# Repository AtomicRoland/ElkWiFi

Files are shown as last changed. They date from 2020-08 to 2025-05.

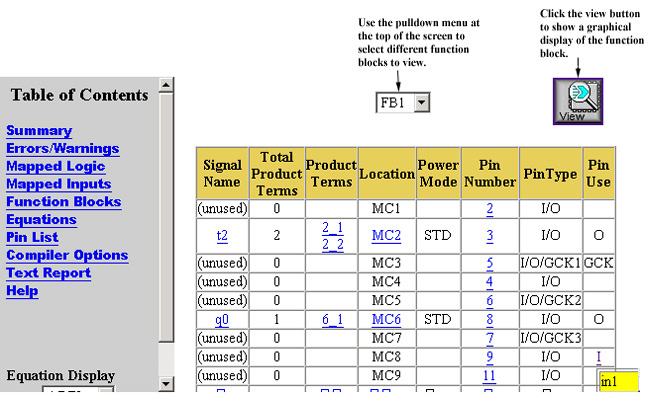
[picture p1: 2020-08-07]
cpld/nco_html/fit/xml5.jpg

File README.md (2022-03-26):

# Introduction

This project is a WiFi interface module for the Acorn Electron. It's a cartridge that fits into a Plus-1 socket. The cartridge contains a ROM for the necessary drivers and utility commands. There's also 128 kB paged RAM available for buffering and storing incoming data. The WiFi is handled by the famous ESP8266 module. This is controlled by a dual UART 16C2552.

# WARNINGS

## 1. Security
The Acorn Electron is in no way a secure device, nor is the software for the WiFi module. When using the commands or driver, usernames and passwords may be kept in memory.

## 2. Baud rate changes may brick the ESP8266
The default transmission speed for the ESP8266 is 115,200 baud. The Electron can handle data transfers at this speed. Do not try to change this speed because the ESP8266 might accept your command but does not always perform it correctly. You might end up with a module that communicates at an unknown serial speed. The only remedy to fix that is to flash the device (or replace it, after all, they cost only about £1.00).

# COMPATIBILITY

This cartridge is tested with an Acorn Electron and a standard Acorn Plus-1 expansion module. It is also tested with an Acorn Plus-1 and a Pres Plus-1 ROM. Both configurations work perfectly.

*Known issues:*
 * With a Pres AP6 ROM in a Plus-1 there is a slight corruption on the screen after a hard reset. The cartridge still works as expected.
 * The CPLD is configured to detect whether it is installed in a BBC Master computer. The software is written without using  Electron specific hardware and functions so it is expected to work in a BBC Master. However, this is not tested yet.
 * Neither is any compatibility tested with a disc system, the Tube and Econet interface. They probably won’t work correctly together.
 * This board clashes also with the AP5 extension for the Electron as both boards drive (part of) page &FC and page &FD.

# Useful commands

Command | Description
------- | -----------
DATE		|	display date
IFCFG	  |	display network information
JOIN		|	connect to a wireless network
LAP			| get a list of access points
LAPOPT	|	set options for lap command
LEAVE	  |	disconnect from current network
MODE		| select operating mode
PRD			| dump contents of paged ram
REWIND	|	reset UEF pointer
TIME		|	display current time
UPDATE	|	check for updates
VERSION	| display firmware information
WGET		|  retrieve a file from the Internet
WICFS		|  Activate WiCFS
WIFI		|	interface control

# Support

More information can be found in the manual in the doc directory. Please post your questions, remarks, compliments etc on the StarDot forum at https://stardot.org.uk/forums.

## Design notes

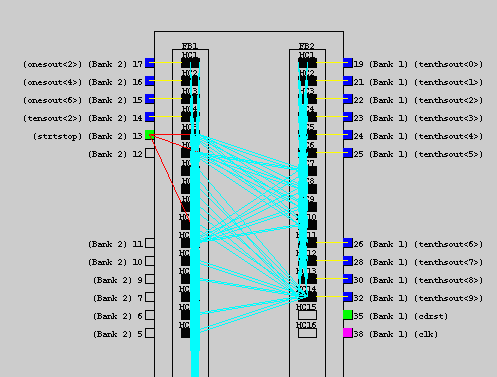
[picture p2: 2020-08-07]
cpld/nco_html/fit/fb.gif

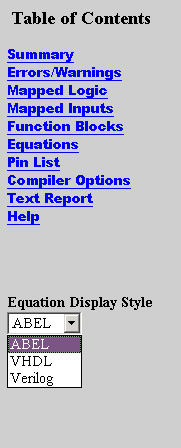
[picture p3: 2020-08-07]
cpld/nco_html/fit/xml8.jpg

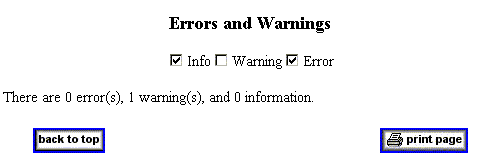
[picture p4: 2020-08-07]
cpld/nco_html/fit/errors2.gif

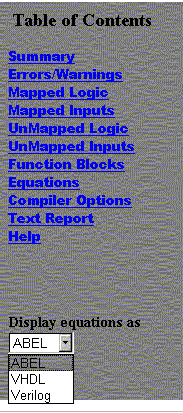
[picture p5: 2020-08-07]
cpld/nco_html/fit/equations.gif

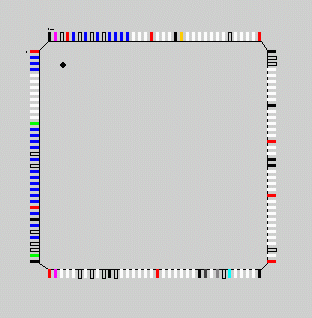
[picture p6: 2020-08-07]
cpld/nco_html/fit/pindiagram.gif

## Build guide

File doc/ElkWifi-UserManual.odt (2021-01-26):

Acorn Electron WiFi

User Manual

Roland Leurs

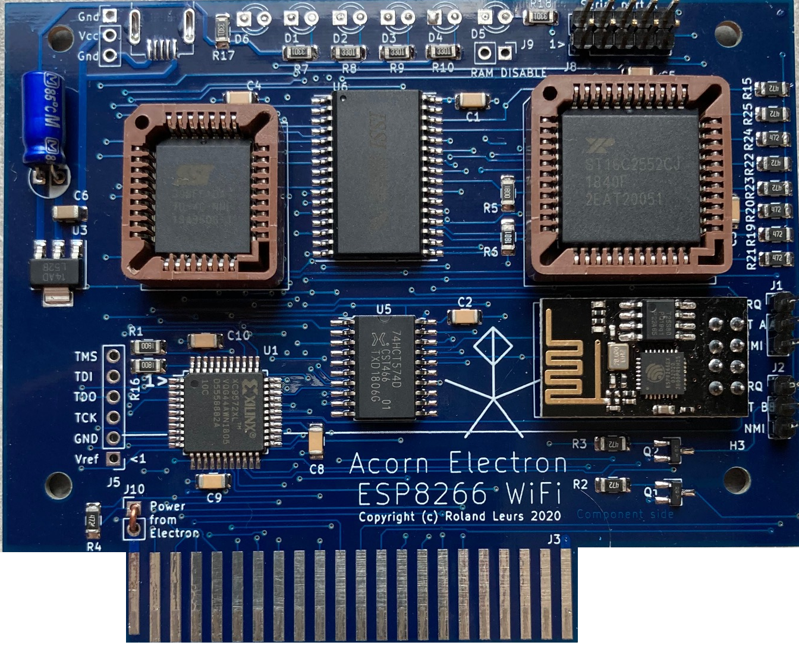
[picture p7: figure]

Copyright (c) 2021 Roland Leurs

january 2020

# Introduction

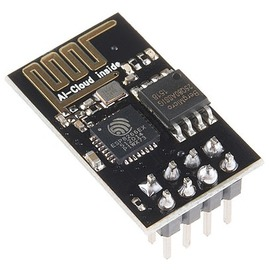
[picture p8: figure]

The ESP8266-01 is (literally) a small device with great possibilities. It enables classic computers and modern micro-controllers to connect to a WiFi network and transmit data via a simple serial interface. Just like bitd it accepts a set of AT commands and performs the necessary actions that are needed for the network communication. The device holds a complete TCP/IP stack, albeit IPv4 only.

So all you need to connect to a wireless network is just a standard serial interface, an ESP8266 and some software.

When I started this project on my Acorn Atom I used the serial port of the Godil and although it basically worked, data transfers were mostly not completed. I never figured out what the reason was, I still suspect my first ESP module (which was another type) was not quite good.

I decided to start a new project with another, even smaller, device (the one you see in the picture above) and I also added an extra serial device. For my Atom 2k18 I could use some additional serial ports since it needs one for communicating with the on-board Pi-Zero and now also for the WiFi device. I picked the 16C2552 which is a dual UART (Universal Asynchronous Receiver and Transmitter) which has two independent communication channels, a 16 byte input / output buffer (FIFO, first in first out) and can transmit up to 4 Mbps. And most important: it is affordable and available from reliable suppliers.

For the Atom I wrote a WiFi driver which can be used by user applications and commands. A basic set of commands include LAP (list access points), JOIN (join a network), TIME/DATE and WGET (to download a file from a web server). All these commands use the same driver. And this setup works nice.

About the time I finished this project the question “Acorn Electron online – any such hardware” popped up on the StarDot forum. And as I had such hardware and software for the Atom, I decided to port both to the Electron.

So here it is, the Acorn Electron WiFi module. An easy to install and use way to connect your Electron to the Internet. I hope you enjoy this device as much as I do.

A warm “thank you” goes to these people of the StarDot community:

- Hoglet, for testing on a Master, generic testing, fault finding and creating a menu system.
- DaveH, for generic testing and reviewing the manual and working on a 3D-printed case.
- MartinB for sharing the sources of UPCFS which made WiCFS possible.
- Multiwizard for end-user testing and creating a do-it-yourself case.

# WARNINGS

Before I continue I have some important warnings:

### 1. Security

The Acorn Electron is in no way a secure device, nor is the software for the WiFi module. When using the commands or driver, usernames and passwords may be kept in memory.

### 2. Baud rate changes may brick the ESP8266

The default transmission speed for the ESP8266 is 115,200 baud. Both the Atom and the Electron can handle data transfers at this speed. Do not try to change this speed because the ESP8266 might accept your command but does not always perform it correctly. You might end up with a module that communicates at an unknown serial speed. The only remedy to fix that is to flash the device (or replace it, after all, they cost only about £1.00).

### 3. Only for personal, domestic use

Both the hardware and software are not designed for medical- and health use nor for mission critical, industrial and automotive purposes. Use it at your own risk.

# Hardware description

The complete diagram is included at appendix I. I will describe my design considerations and the components in this chapter.

### Design considerations

The Electron is a wonderful, small and very sophisticated computer. To keep it small and affordable, Acorn used a very unusual method of accessing the memory. Instead of using 32k x 8 memory chips they used 64k x 4 chips. This means that accessing the memory by the CPU needs two read cycles of 4 bits. This is all taken care of by the ULA, from the programmers point of view, it just behaves like 8 bit memory. A drawback is that accessing the RAM is slow. I did some tests and even at 1200 baud I suffered lost data from the serial interface.

Another issue is that the Electron has not much memory. In the lowest text mode it has only about 20kB of RAM available. This implies that the received data must be processed and stored as soon as it comes in. Even an 8 MHz 6502 is not fast enough to do all the necessary checks and actions within 80 μs (the time that a complete byte is received at 115,200 baud). So we need a buffer that is fast and large. There are two ways to add more memory:

- Add sideway RAM in a bank at &8000-&BFFF This would either imply bank switching during data transfer or add both RAM and ROM to the bank that is used for the software. The memory is also limited to a maximum of 16kB. And that is not very much.
- Add Paged RAM at &FD00-&FDFF Acorn reserved a 256 byte page for memory expansion. This memory is “chopped” in small banks of 256 bytes. With a paged RAM register the program can select a bank. Since this register is 8 bit wide, we have 256 pages. The total memory can be 256 x 256 = 65535 bytes: 64kB. Since this memory is a real 8 bit memory it is large and fast enough. So I added this type of memory to my module.

The paged RAM register should be both writable and readable. I could do this by adding an extra buffer that is enabled when a read cycle occurs at &FCFF (the address of the paged RAM register). But the UART has two scratch pad registers. These behave like a normal memory address. So I use the scratch pad register of the A-channel (which is available for generic serial applications) as a read/write copy of the paged RAM register. The decoding is simply done in hardware so for a programmer the address &FCFF is just a normal register that can be written and read.

If your Electron already has paged RAM at &FDxx then you can disable the memory on the WiFi board by adding a jumper.

To make the WiFi software available without loading it from tape, disk or memory card I also added an EEPROM to the board. The WiFi is available directly after powering on the Electron.

Both the RAM and the EEPROM are 128kB and although memory is cheap these days it is also a pity if we can’t use it to the max. For both memory chips I connected the Multi Function output of the serial ports to an address line (A15 of the EEPROM, A16 of the RAM). This way the usable memory capacity is doubled without any extra hardware. It is important to know that as soon as MFA (the extra address line of the EEPROM) is changed, the sideway ROM banks also change without notifying the operating system. This can lead to a hanging Electron when the operating system knows that there was a ROM during boot time. So use this with extreme caution. It is most unlikely that switching will damage your Electron.

### Circuit description

The circuit has the following blocks:

1. Power supply The board gets its +5V from the edge connector and so it is powered by the Electron. Therefore J10 should be closed. Normally this is not a jumper but a fixed wire bridge. It is possible to power the board from an external power supply, e.g. via an USB smartphone loader but before mounting the connector you should remove the link in J10!
2. CPLD: Control logic and level shifting The ESP8266 is a 3.3V device but it is connected to the UART which is a 5V device. This is no issue for the receiving line but the transmitting line must be converted from 5V to 3.3V. So the RX input of the ESP8266 is not directly connected to the UART but to the CPLD.  The CPLD also controls the RX and TX LEDs. Since the data transfer is quite fast, the human eye might miss some visual feedback. The CPLD is triggered by a level change at each RX and TX input and will light the according LED for 0.10 seconds.  The most important function of the CPLD is the control logic. Most inputs are directly taken from the edge connector and converted to the necessary control signals for accessing the devices on the board.
3. RAM The RAM is directly controlled from the Plus-1 (signal: nPGFD). The RD and WR signals are controlled by the CPLD. Address lines A0-A7 are also directly connected to the edge connector and A8-A15 are connected to the paged RAM register. A16 is connected to the MFB output of the UART to add another bank of 64kB RAM.  Selecting a page is as easy as writing to the paged RAM register. After a (power on) reset the paged RAM register and the copy in Scratch Pad Register B are probably out of sync. Before using the paged RAM the program should synchronize these by simply writing a value to &FCFF.  The onboard RAM can be disabled by closing J9. This disables only the RAM, the paged RAM register is still in use, just like the shadow copy in the Scratch Pad Register[^1].
4. EEPROM The EEPROM is controlled by the CPLD. However, it is addressed to &8000-&BFFF and the ROMQA signal is connected to A14. In this setup it provides two banks of sideway ROM. A15 is connected to MFA which makes it possible to activate another set of two banks. This should be used with care, like described in the design considerations.
5. UART: the serial device The UART is the interface between the CPU and the ESP8266. It has two independent channels. Channel A is unused by the WiFi board and can be used as a normal serial device. J8 has all the standard data and control signals plus an additional 5V. With a small extra interface you can directly connect a level converter for creating a real RS232 or RS432 interface. The Scratch Pad Register of channel A is used as a copy of the paged RAM register; Multi Function output A is used as an extra address line for the EEPROM (see above). Channel A is located at &FC38-&FC3F (hence the choice of SPR#A for the register copy: all lower address lines are ‘1’).  Channel B is exclusively used for the WiFi interface. The RX and TX lines are for data communication. The other modem control signals are also used: * DTR#B → enable/disable the ESP8266 * RTS#B → reset the ESP8266 * MF#B → extra address line for the paged RAM * RI#B → paged RAM status: enabled or disabled So it is possible to give the ESP8266 a real hardware reset, just in case it does not respond to any command. Just toggle the RTS line from high to low by writing a ‘1’ value to the corresponding bit in the modem control register. And of course, set is back to a high level by writing a ‘0’ to the modem control register. In a similar way it is also possible to disable the ESP8266. Just make the DTR output low by writing a ‘1’ to the corresponding bit in the modem control register. On a hardware reset of the UART this register is reset to all ‘0’ so the WiFi module becomes enabled again. To prevent this, you can write any value to the Line Status Register. This is unused in the UART device itself but it sets a flag inside the CPLD. This flag will prevent the CPLD to activate the RESET line to the UART. By writing any value to the Modem Status Register this flag will be cleared and reset signals are passed to the UART.
6. ESP8266 The module will be fitted as an add-on to the board. To prevent a physical clash between the ESP8266 and the Plus-1 it is soldered directly to the board. Exchanging the ESP8266 will be a bit complicated so remember not to change the baud rate (see chapter ‘warnings’).

# Installation

Since the module is build and tested it is directly ready for use. Turn off your Electron. Plug the WiFi board into a free slot of the Plus-1 and power on your Electron. It should start with a banner like “Acorn Electron WiFi”. A special WiFi symbol will be displayed whenever the module is enabled. If the WiFi symbol does not occur you can enable the WiFi module with the command

*WIFI ON

If you don’t see the WiFi banner at all then reinstall the module.

# Software

The ROM contains a set of new * commands and a driver for the ESP8266 module. In the next section I describe the new commands. The driver functions are described later in this manual. Please not that you cannot access the driver functions directly; there is an OSWORD call for accessing these functions from your own applications.

### DATE display date

Syntax: *DATE

This commands fetches the current date from the Internet. It fetches a special page from http://acornelectron.nl to get the current time and date.

### DISCONNECT disconnect from a server

Syntax: *DISCONNECT

You can use this command to disconnect from a server if the connection stays open due to an error condition. Most commands do automatically close their connection to the server but sometimes they stay open. When you get a message “Already connected” you can use *DISCONNECT to close the connection.

To disconnect from a wireless network use *LEAVE.

### IFCFG display network information

Syntax: *IFCFG

Use this command to show the current assigned IP address and the MAC address of your ESP8266. This command cannot be used to manually set your IP configuration.

### JOIN connect to a wireless network

Syntax: *JOIN <ssid> [password]

In order to use the network functions you must first join a WiFi network. Use this command to join a network. The <ssid> is a required parameter. If you don’t supply a password on the command line then you will be prompted to enter the password. Please keep in mind that both the ssid and the password are case sensitive and that the password might remain in the Electron’s memory!

The command *JOIN ? will show you to what network you are currently connected to.

### LAP get a list of access points

Syntax: *LAP

This commands shows a list of access points. By default it shows this information for each access point:

+CWLAP:<ecn>, <ssid>, <rssi>, <mac>, <ch>, <freq offset>, <freq cali>

where

<ecn> = Encryption 0: OPEN, 1: WEP, 2: WPA_PSK, 3: WPA2_PSK, 4: WPA_WPA2_PSK

<ssid> = Network Id

<rssi> = Signal strength

<mac> = MAC address of access point

<ch> = Channel

<freq offset> = frequency offset of access point in KHz

<freq cali> = calibration for frequency offset

You can change this information with LAPOPT. The list of networks is always sorted by signal strength (rssi).

### LAPOPT set options for lap command

Syntax: *LAPOPT <option>

The option is a binary value with each bit representing what field will be shown when you use *LAP:

bit 0 sets whether <ecn> will be shown

bit 1 sets whether <ssid> will be shown

bit 2 sets whether <rssi> will be shown

bit 3 sets whether <mac> will be shown

bit 4 sets whether <ch> will be shown

bit 5 sets whether <freq offset> will be shown

bit 6 sets whether <freq calibration> will be shown

So, for example, *LAPOPT 7 will only show the encryption type, the name (ssid) and signal strength (rssi) of the available WiFi networks.

### LEAVE disconnect from current network

Syntax: *LEAVE

Disconnects you from the wireless network.

### MENU start games menu

Syntax: *MENU

This command downloads a menu program to &E00 and starts it. So make sure your PAGE is at &E00, if necessary disable your DFS,

MMFS etc.

A list of games is retrieved from acornelectron.nl. You can browse through this list with the cursor up/down keys or start searching for a title by pressing the / key.

The selected game is loaded as an UEF file. There are more than 700 games files available but not all files are tested and working.

### MODE select operating mode

Syntax: *MODE <1...3>

The ESP8266 can operate as a WiFi station (client) or as an access point (server) or both. With the *MODE command you can select the operation mode:

1 → station mode

2 → SoftAP mode

3 → SoftAP and station mode

The mode is also stored into the device’s flash configuration and will remain until it is changed. When a new device is first powered on and it won’t respond to commands it is probably not configured as a station. Setting mode to 1 will solve that issue.

With *MODE ? you can query the current mode of the device.

### PING ping to a host

Syntax: *PING <host or ip-address>

You can test internet connectivity with this command or test whether a host is reachable. This command will send five “ping” packets and waits for the response from the remote host. When successful it will display the response time. If the host is not reachable then you will get a “No response from host” message. In case that the host does not exist or other failures you will see a “Host error” message.

### PRD dump contents of paged ram

Syntax: *PRD <address> <bank nr>

PRD stands for “Paged RAM Dump”. This command is used to inspect the contents of the paged RAM. The address is a 16 bit value with the most significant byte being the page number and the least significant byte is the offset within the page. The bank number is either 0 or 1 and selects the bank that you want to dump. The current bank number is always saved and restored after the dump command is finished. You can stop the dump by pressing the <ESC> key.

### PRINTER enable WiFi printing

Syntax: *PRINTER N:<printer name or ip-address>
*PRINTER S:baudrate,parity,data bits,stop bits
*PRINTER OFF

This command activates or stops the WiFi printer drivers. It’s still experimental so it might contain several bugs. See chapter “WiFi printing” for more information.

### REWIND reset UEF pointer

Syntax *REWIND

Resets the pointer of an UEF file to the beginning of the file. See chapter “Working with UEF files” for more information.

### SETSERIAL set up serial port A

Syntax: *SETSERIAL baudrate,parity,data bits,stop bits

The WiFi board has a dual port UART for general purpose usage. With this command you can setup the serial interface. Parameters are:

baudrate any (usual) baud rate between 300 and 115,200 baud
parity O(dd), E(ven), N(one), 1 or 0 sets the parity
data bits use 5, 6, 7 or 8 for the word length
stop bits use 1 or 2 for the number of stop bits

### TIME display current time

Syntax: *TIME

Like the *DATE command, you can also query the current time. See *DATE for additional information.

### UPDATE check for updates

Syntax: *UPDATE [-R]

To facilitate easy updates of the Electron WiFi ROM you can use the *UPDATE command. If there is a newer version of the ROM available then you can download and install it with a single key press. When a newer version is found on the server then you will be prompted “There is an update available. Do you want to install it (y/N/R)?”. To install the update press ‘y’ (in lower case!) to start the update. Then, the newer ROM image will be downloaded and if the CRC16 of the downloaded image matches the CRC16 on the server then the EEPROM (only the WiFi part) is erased. After erasing, the new version will be “burned” into the EEPROM. Then routine ends with a simulated hard reset of the Electron to re-initialize the new ROM.

Warning: the new version will be downloaded in the memory area &2000 - &5FFF. So save any data before downloading the update!

Do not power off or interrupt the update process as this might leave your ROM in an unusable state. If you brick your ROM then see appendix 2 for a possible fix.

Please note that this software does not support any kind of update of the ESP8266 module, nor can the CPLD be updated with this tool.

If you use the optional parameter -R you will see a text file with the release notes for the latest versions. This overview is also shown when you press R after the question if you want to update. With the -R option the ROM will not be updated.

### VERSION display firmware information

Syntax: *VERSION

This command retrieves the firmware version of the ESP8266 module.

### WGET retrieve a file from the Internet

Syntax: *WGET [-T X U A P S] <url> [load address]

This tool downloads a file from a web server and either displays it on the screen (for example a text file) or stores it in the Electron’s memory.

The tool has three parameters. The first one is an optional switch to indicate the file type. You may only specify one of these switches:

-T treat the file as a text file and display it on the screen after downloading the file. It will not be stored in the Electron’s main memory.

-X this is the same as -T but it uses the code &0A as newline. Suitable to display Linux/Unix files.

-A the file will be downloaded into the Electron’s memory and has an ATM file header. If no load address is specified on the command line, the file will be stored on the load address in the header.

-P similar to the -A option, but now the file has an Atom-in-PC header. If no load address is specified on the command line, the file will be stored on the load address in the header.

-U the file is an UEF file. This file will be loaded into the second 64k bank of the paged RAM.

-S the file a a ROM file and will be loaded directly into sideways RAM. You should specify the RAM bank number (0 – F) as the last parameter; the default is bank 0.

The URL consists of a number of components:

protocol (required, http and https are supported
protocols)

hostname (required)

port number (optional)

path and filename (optional)

For example: http://acornlectron.nl:8080/path/to/file.htm

Although you can specify https as a protocol and the ESP8266 will connect to port 443 of the web server, it does not retrieve any data. This is probably related to either outdated encryption protocols or the ESP8266 might not support SNI.

The last parameter, load address, will override the load address that is in a header. If this parameter is omitted and the file has no header then it will be loaded at the current PAGE.

### WICFS Activate WiCFS

Syntax: *WICFS

WiCFS is an emulated cassette filing system using an UEF file as data source. This commands sets PAGE to &E00 and sets vectors FILEV, FSCV, FINDV and BGETV. See chapter “Working with UEF files” for more information.

### WIFI interface control

Syntax: *WIFI [ on | off | sr | hr ]

This command accepts one of these parameters:

on enables the WiFi device

off disables the WiFi device

sr performs a software reset of the ESP8266 by
issuing an AT+RST command

hr performs a hardware reset of the ESP8266 by
toggling the RTS line of the UART

# Driver functions

The communication with the ESP8266 is done with a few standard functions. So there is no need to use any of the AT commands in user applications. If you write an application that needs some features that are not in the driver then please report this and it can be added to the driver. This way we can assure compatibility whenever another WiFi device will be used.

The driver supports these functions[^2]:

Function | AT command | Short Description
00 | AT+RST | Initializes the ESP8266 (soft reset)
01 | n/a | Hard reset
02 | AT+GMR | Get firmware information
03 | AT+CWLAP | Get list of access points
04 | AT+CWJAP | Join access point
05 | AT+CWQAP | Quit access point
06 | Not implemented | Set access point parameters
07 | AT+CWMODE | Set device mode
08 | AT+CIPSTART | Connects to host
09 | AT+CIPMUX | Activate multiplex (up to five channels)
10 | Not implemented | List joined interfaces
11 | Not implemented | Set buffer address (old Atom driver)
12 | AT+CIPSTATUS | Get TCP/IP connection status
13 | AT+CIPSEND | Send data to remote host
14 | AT+CIPCLOSE | Close connection to remote host
15 | Not implemented | Set as server
16 | Not implemented | Set time out
17 | AT+CIOBAUD | Get baud rate (set baud rate is not implemented)
18 | AT+CIFSR | Get IP and MAC address
19 | Not implemented | Get firmware update
20 | IPD | Transfer data
21 | AT+CSYSWDTENABLE | Enable watchdog timer
22 | AT+CSYSWDTDISABLE | Disable watchdog timer
23 | n/a | Get multiplexer channel
24 | n/a | Enable/disable WiFi device
25 | AT+CWLAPOPT | Set options for LAP function
26 | AT+CIPSSLSIZE | Set SSL Buffer size
27 | AT+CIPMODE | Set transmission mode
28 | AT+PING | Perform ping command

### Function 00 Soft reset

Parameters: none

This function sends a software reset command to the WiFi device. The device will reinitialize itself.

### Function 01 Hard reset

Parameters: none

This function performs a hardware reset by toggling the RTS line from high to low and back to high.

### Function 02 Get firmware information

Parameters: none

This function retrieves the firmware version from the WiFi device.

### Function 03 Get list of access points

Parameters: none

This function retrieves a list of all wireless SSID’s in the neighborhood. The response is like:

+CWLAP:<ecn>, <ssid>, <rssi>, <mac>, <ch>, <freq offset>, <freq cali>

where

<ecn> = Encryption 0: OPEN, 1: WEP, 2: WPA_PSK, 3:
WPA2_PSK, 4: WPA_WPA2_PSK

<ssid> = Network Id

<rssi> = Signal strength

<mac> = MAC address of access point

<ch> = Channel

<freq offset> = frequency offset of access point in KHz

<freq cali> = calibration for frequency offset

See function 25 for LAP options. The ESP8266 might receive additional parameters for the AT+CWLAP command but these are not supported by this driver.

### Function 04 Join access point

Parameters: X points to the high byte of a parameter block

Y points to the low byte of a parameter block

The parameter block holds two adjacent strings which are terminated with a &0D byte. The first string is the SSID of the access point and the second string is the password for that access point. Both strings should not contain quotes and are case sensitive.

On success the WiFi device is connected to the wireless network and gets an IP address. This connection is permanently stored in the device so it connect automatically to this network after the next (power on) reset.

### Function 05 Quit access point

Parameters: none

This functions disconnects the WiFi device from the wireless network.

### Function 07 Set device mode

Parameters: X = hi byte param block

Y = low byte param block

The ESP8266 has three operation modes:

1 → station mode

2 → SoftAP mode

3 → SoftAP and station mode

Note that these values are not binary values but the ASCII values.

X and Y point to a parameter block in memory with the requested mode, terminated with &0D. If the parameter block is an empty string it will query the device for the current mode.

The mode is also stored into the device’s flash configuration and will remain until it is changed. When a new device is first powered on and it won’t respond to commands it is probably not configured as a station. Setting mode to 1 will solve that issue.

### Function 08 Connect to remote host

Parameters: X = hi byte param block

Y = low byte param block

The parameter block contains the following information, presented as strings terminated by &0D:

<link ID> (but only when multiplexing is active)

<type> (UDP, TCP or SSL)

<remote IP> (or hostname)

<remote port>

No quotes are allowed around these parameters. On success the device responds with CONNECTED crlf crlf OK crlf crlf. On failure it will respond with an error message, such as already connected or DNS failure etc.

### Function 09 Multiplexing control

Parameters: Y = multiplexing on (1) or off (0)

This function initializes the multiplex workspace for the driver and sends the multiplexer value to the ESP8266. This value might be both the ASCII value or the binary value.

### Function 13 Send data to remote host

Parameters: X points to data block in zero page

Y = channel (note to myself: this is not implemented yet!)

This data block holds two addresses:

- two bytes start address of data (low byte / high byte)
- two bytes length (low byte / high byte)

### Function 14 Close connection to host

Parameters: Y = channel (only when multiplexing is
active, otherwise ignored)

Some servers or services close the connection after responding to function 13. So it is advised to always call this function after a transfer has completed. If the connection is already closed by the server then this function will end with an error that might be ignored.

### Function 18 Get IP and MAC address

Parameters: none

This function retrieves the current IP address and MAC address of the ESP8266 device.

### Function 23 Get multiplexer channel

Parameters: none

You can use this function to request a free channel from the driver. Multiplexing must be enabled with function 09. This function responds with one of the following:

Carry cleared: Y = 255; multiplexing is switched off

Carry set: Y = 255: no free channel

Carry set: Y <> 255: assigned channel number

### Function 24 Enable/disable wifi device

Parameters: X = 0: disable WiFi, X = 1: enable WiFi

This function causes the UART to pull DTR low and so it disables the ESP8266. It also configures the CPLD to prevent that the UART is reset after pressing the BREAK key. So, if WiFi is disabled it will be disabled even after a (hard) reset. After a power off/power on reset it will be enabled again.

### Function 25 Set options for LAP function

Parameters: to be determined….

This sets the options which fields will be returned by the LAP function:

bit 0 sets whether <ecn> will be shown

bit 1 sets whether <ssid> will be shown

bit 2 sets whether <rssi> will be shown

bit 3 sets whether <mac> will be shown

bit 4 sets whether <ch> will be shown

bit 5 sets whether <freq offset> will be shown

bit 6 sets whether <freq calibration> will be shown

### Function 26 Set SSL Buffer size

Parameters: none

This function sets the SSL buffer size to a fixed value of 4096.

The “receive data” routine is written in a way that it does not use any main memory of the Electron. It avoids instructions that change the stack (like JSR and PHA). So it only uses the ROM and paged RAM. This way, the CPU can run at full 2 MHz and is fast enough to read and store the incoming data. For graphical modes 0 to 3 it also disables interrupts, since these will make the CPU access the stack. In modes 4 to 6 the UART FIFO is large enough to buffer the incoming data during the execution of the interrupt service routine. So the WiFi functions can be used in any graphics mode.

### Function 27 Set transmission mode

Parameters: X = hi byte param block

Y = low byte param block

UART-WiFi pass-through mode (transparent transmission) can only be enabled in TCP single connection mode or UDP of which remote IP and port won’t change (parameter <UDP mode> is 0 when using command "AT+CIPSTART" to create a UDP transmission).

During UART-WiFi pass-through transmission, if it is TCP connection and the TCP connection breaks, ESP8266 will keep trying to reconnect until "+++" is inputed to quit from transmission. After "+++",

please wait at least 1 second before sending next AT command.

If it is a normal TCP transmission and TCP connection breaks, ESP8266 will prompt " [<link ID>, ] CLOSED" , and won’t try to reconnect. Users can call "AT+CIPSTART" to create a connection again if it’s needed.

The parameter block contains a string holding the new mode; this is a single character string with a terminating &0D character:

Value 0: normal operating mode

Value 1: pass-through mode

Both values are the ascii characters for 0 and 1.

### Function 28 PING

Parameters: X = hi byte param block

Y = low byte param block

The parameter block contains a string with the hostname or an IP address of the host you want to ping. This string is terminated by &0D.

The result of the ping is one of the following:

+<time> the response time in ms

+timeout a time-out occurred

error a generic message that ping failed

# Using the driver: OSWORD &65

Since you cannot access the WiFi driver functions directly, you can use this operating system call to get access to the driver.

Like any other OSWORD call the A register contains the function number (&65) and the X (lsb) and Y (msb) registers point to a parameter block. This parameter block is always three bytes and contains the parameters for the driver functions:

first byte: the driver function number (A)

second byte: the value for the X register

third byte: the value for the Y register

Example:

You want to connect to a wireless network. So you store the ssid and password in memory at &680. The parameter block will be stored at &600.

To connect to the network do:

LDA #&04 \ load driver function

STA &600 \ write to first byte of driver parameter block

LDA #&06 \ load X value for function

STA &601 \ write to second byte of driver parameter block

LDA #&80 \ load Y value for function

STA &602 \ write to third byte of driver parameter block

LDX #&00 \ load X register with low byte of parameter block

LDY #&06 \ load Y register with high byte of parameter block

LDA #&65 \ load OSWORD function number

JSR &FFF1 \ do OSWORD call

# Working with UEF files

Unified Emulator Format (UEF) is a container format for the (un)compressed storage of audio tapes, ROMs, floppy discs and machine state snapshots for the 8-bit range of computers manufactured by Acorn Computers. First implemented by Thomas Harte's ElectrEm emulator and related tools, it is now supported by major emulators of Acorn machines. Martin Barr wrote UPCFS which is a tool that reads UEF files from a PC using an UPURS connection.

UEF attempts to concisely reproduce media borne signals rather than simply the data represented by them, the intention being an accurate archive of original media rather than merely a capability to reproduce files stored on them. A selection of metadata can be included, such as compatibility ratings, position markers, images of packaging and the text of instruction manuals. UPCFS only supports file data.

With WiCFS I ported UPCFS to the WiFi ROM. Only a few changes were necessary, mainly fetching the data from memory rather than from a serial connection.

### Downloading an UEF file

Before you can use an UEF file you have to download it from a (local) web server. Use the *WGET command for this with the -U switch, for example:

*WGET -u http://acornatom.nl/ddd.uef

This will download the UEF file and store it in the second bank of 64k paged RAM. At the moment only uncompressed files are supported. The uncompressed UEF should not exceed 65533 bytes (the last two addresses are used to store the length of the UEF file).

### Starting the WiCFS filing system

After loading the UEF file you can start the WiCFS filing system with the command:

*WICFS

This command activates *TAPE but changes the vectors FILEV, FSCV, FINDV and BGETV to its own routines. Commands like *CAT, *LOAD and *RUN are intercepted and redirected to the WiFi ROM. Page is set to &E00 as this is required for many games.

Also the read-pointer is reset to the beginning of the data.

### Rewinding

Just like a real tape you might sometimes need to “rewind” the data in memory. Of course we are not moving the data around but we have to move the read-pointer to the beginning of the data in memory.

After you have *CAT-ted an UEF file you must reset the read-pointer to the beginning of the file before you can load a file into the main memory of your Electron. That’s all what the

*REWIND

command does.

### Tape analogies

To place a tape into the recorder: *WGET -U <url>

Switch on the tape recorder: *WICFS

Rewind the tape: *REWIND

Just like tapes, you might switch to another UEF file by issuing another WGET -U command. And just like real tapes you have to rewind it with *REWIND before accessing files otherwise you might get read errors.

You can compare the read-pointer at the UEF with the tape position just below the magnetic head of your cassette recorder.

# Printing with the WiFi board

Note: this functionality is still under development. Please consider this chapter as preliminary information.

The WiFi board has two interfaces to connect a printer:

1. The serial port A of the UART
2. The network interface

Keep in mind that modern printers need both a CR and LF for a new line. Old dot matrix printers often needed only CR. To enable a line feed use the command *FX 6,0

### Connecting a serial printer

To connect a serial printer you need an additional adapter to convert the TTL logic signals to real RS-232 levels in both directions. The serial port on the board has a +5V pin for this purpose. Such a conversion board is not covered in this manual.

To enable the serial printer you start with the command:

*PRINTER S:<baud rate>,<parity>,<data bits>,<stop bits>

where

baud rate any (usual) baud rate between 300 and 115,200 baud
parity O(dd), E(ven), N(one), 1 or 0 sets the parity
data bits use 5, 6, 7 or 8 for the word length
stop bits use 1 or 2 for the number of stop bits

This command only enables the printer driver but it does not select the serial printer. To select the serial printer you use the *FX 5,6 command. The number 6 is the hard coded printer ID in the WiFi ROM for both the serial and network printer. After you selected the serial printer you can start printing with VDU 2 (or CTRL+B) and stop printing with VDU 3 (or CTRL+C).

The serial printer drivers is not tested and lacks any kind of handshake. It simply outputs all the data to the serial port and the printer should be able to receive and buffer the data. For fast printers or printers with a large buffer this won’t be an issue, but a slow dot matrix printer might suffer data loss.

If you need any kind of handshake, we’ll have to add it to the driver. Both software handshake with XON/XOFF and hardware handshake with CTS/RTS can be implemented.

### Printing to a network printer

To use a network printer you need a printer that is compatible with the HP JetDirect interface. Most Hewlett Packard network enabled printers have such an interface but also many other manufacturers have printers with a compatible interface.

This interface accepts raw data and will print in a standard courier font. By sending the appropriate PCL commands you can also use more advanced features of your printer. PCL is not covered in this manual.

Printing over SMB (for printing to a shared printer on a Windows host) or LPD is not supported; printing goes directly to the network attached printer.

Before you can print to a network printer you have to enable the printer driver with:

*PRINTER N:<printer name or IP address>

This command only enables the printer driver but it does not select the network printer. To select the network printer you use the *FX 5,6 command. The number 6 is the hard coded printer ID in the WiFi ROM for both the serial and network printer. After you selected the network printer you can start printing with VDU 2 (or CTRL+B) and stop printing with VDU 3 (or CTRL+C).

While printing the ESP8266 module is put into pass-through mode. Every byte received over the serial interface is directly passed on to the network. A disadvantage of pass-through mode is that it is not supported with multiplexing active. So you cannot use the WiFi commands during printing. If the printer is not active, the WiFi command can be used.

So, this won’t print the book of Winnie the Pooh:

*PRINTER N:OKI.RLS.TRIPPLER.NL
*FX 5,6
VDU 2
*WGET -X http://acornelectron.nl/winnie-the-pooh.txt
VDU 3

### Disable the printer driver

To disable the printer driver, simply type: *PRINTER OFF

# Appendix I: part list and circuit diagram

# Appendix II: recovering a bricked WiFi ROM

In case the update process is interrupted or crashed, you can manually try to re-program the ROM. You need three files, that you can download from a web server:

http://acorn (http://acornatom.nl/atomwifi/elkwifi-latest.bin)electron (http://acornatom.nl/atomwifi/elkwifi-latest.bin).nl/wifi/elkwifi-latest.bin (http://acornatom.nl/atomwifi/elkwifi-latest.bin)
this is the 16kB ROM image, load at &2000

(http://acornatom.nl/atomwifi/erase.bin)

http://acorn (http://acornatom.nl/atomwifi/erase.bin)electron (http://acornatom.nl/atomwifi/erase.bin).nl/wifi/erase.bin (http://acornatom.nl/atomwifi/erase.bin)
this is an erase tool, load at &1E00

(http://acornatom.nl/atomwifi/program.bin)

http://acorn (http://acornatom.nl/atomwifi/program.bin)electron (http://acornatom.nl/atomwifi/program.bin).nl/wifi/program.bin (http://acornatom.nl/atomwifi/program.bin)
this is a programming tool, load at &1F00

It’s your own challenge to get these files into your Electron’s memory without a WiFi connection. At some point in time I will provide a SSD image that can be opened with one of the many MMC storage solutions.

If these three files are loaded into your Electron’s memory do:

CALL &1E00 to erase the EEPROM bank (break may be

needed after flashing)

CALL &1F00 to program the latest image into the EEPROM bank

Two important remarks:

1. Load all the three files into the Electrons memory if you need to transfer them over WiFi
2. This procedure only works with the cartridge in the rear slot of the Plus-1

# Appendix III: compatibility

This cartridge is tested with an Acorn Electron and a standard Acorn Plus-1 expansion module. It is also tested with an Acorn Plus-1 and a Pres Plus-1 ROM. Both configurations work perfectly.

Known issues:

- With a Pres AP6 ROM in a Plus-1 there is a slight corruption on the screen after a hard reset. The cartridge still works as expected.
- The CPLD is configured to detect whether it is installed in a BBC Master computer. However, the software does some access to page &FExx so there are some compatibility issues with this card in a BBC Master computer.
- Neither is any compatibility tested with a disc system, the Tube and Econet interface. They probably won’t work correctly together.
- This board clashes also with the AP5 extension for the Electron as both boards drive (part of) page &FC and page &FD.
- Not all games are compatible with WiCFS. A list of known working games is at: https://www.retro-kit.co.uk/page.cfm/content/UPCFS-Working-titles/

You can send your feedback to: roland@acornatom.nl

# Appendix IV: Memory usage

The hardware uses the following addresses in the Electron memory map:

&FC30-&FC37 UART Port B (used by WiFi)

&FC38-&FC3E UART Port A (available to user)

&FC3F read back of paged RAM register

&FCFF paged RAM register

&FD00 - &FDFF paged RAM

The software uses the following addresses:

&0090 - &0096 permanent storage in page 0

&00B0 - &00CF temporary workspace in page 0

&0100 - &0140 temporary workspace for error handling

&0398 - &03FF used by WiCFS

&07A4 - &07FF used by WiCFS

&0900 - &0AFF temporary workspace for WiFi commands

&8000 - &AFFF sideway ROM in either slot 0 or 2

# Appendix V: License

The license for this Work (i.e. both the hardware and software) are simple:

1. You have the right to use the Work in any way you want for non-commercial use. Commercial use is considered when you integrate the Work into your own products or replicate the Work and sell it.
2. You may create your own hardware and software based on the Work for non-commercial use. However, for deviated projects you must use the same license.

Warranties and Disclaimer

Except as required by law, the Work is licensed by the Licensor on an "as is" and "as available" basis and without any warranty of any kind, either express or implied.

Limit of Liability

Subject to any liability which may not be excluded or limited by law the Licensor shall not be liable and hereby expressly excludes all liability for loss or damage howsoever and whenever caused to You.

[^1] Note to myself: this disable signal can be connected to pin 1 of the CPLD. This way the CPLD can also disable the paged RAM register.
[^2] Well, supports almost all of these functions. Some functions are not implemented yet.

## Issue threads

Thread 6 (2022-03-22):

Cannot connect to network with spaces in the network name

AtomicRoland, 2022-03-22:
Like the title suggests: if there's a space in the network name you cannot connect to a wireless network. For example when the name of the network is _Atomic Guests_  If you perform *JOIN Atomic Guests then the command will treat Atomic as the network name and Guests as the password.

Possible fix: allow spaces in parameters by using quotes.

AtomicRoland, 2024-11-17:
Fixed in commit a60c6feefbfba0ff7b5d6cf62b4d4931fa013c10, May 2022.

Closed 2024-11-17.

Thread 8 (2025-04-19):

Incompatibility issue with RAMUTILS

AtomicRoland, 2025-04-19:
A user has reported an incompatibility issue with Prime’s RAMUTIL ROM for the Plus3 RAM-board. With this ROM enabled the WiFi board cannot connect to a host.

*TIME and *DATE don’t receive data (udp connection) and *WGET returns a “link type error”.

This is caused by a zero page conflict with address &AA and up. This forces the WiFi board into a multiplex connection with an invalid channel.

AtomicRoland, 2025-05-05:
Bug should be fixed in version 0.34. In this version I disabled multiplexing in the driver to free conflicting zero-page addresses. I've send a message to the issuer of this issue to test if the problem is solved now.

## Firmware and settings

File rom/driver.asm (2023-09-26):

\ Sideway ROM for Electron Wifi board
\ (c) Roland Leurs, May 2020

\ Main service ROM
\ Version 1.00

\ Please note that some functions or routines are not quite logical
\ but they are implemented to keep driver compatibility with the 
\ Atom wifi driver.

.wifidriver
 \ entries are.
 \ 00 init                12 cipstatus
 \ 01 reset               13 cipsend
 \ 02 gmr                 14 cipclose
 \ 03 cwlap               15 cipserver
 \ 04 cwjap               16 cipsto
 \ 05 cwqap               17 ciobaud
 \ 06 cwsap               18 cifsr
 \ 07 cwmode              19 ciupdate
 \ 08 cipstart            20 ipd
 \ 09 cpmux               21 csyswdtenable
 \ 10 cwlif               22 csyswdtdisable
 \ 11 setbuffer           23 getmuxchannel
 \ 24 disable/enable	  25 cwlapopt
 \ 26 sslbufsize		  27 cipmode
 \ 28 ping				  29 time out value

 sta save_a                 \ save registers
 stx save_x
 sty save_y
 cmp #24                    \ check for enable/disable command
 beq wifi_init_uart         \ this is always allowed
 cmp #&FE
 beq flash
 jsr test_wifi_ena          \ test is wifi is enables (in serial.asm)
 beq wifi_init_uart         \ jump if wifi is enabled
 jsr uart_wifi_off          \ redo the disable because sometimes the WiFi gets enabled after a reset
 ldx #(error_disabled-error_table)
 jmp error                  \ throw page ram error
.wifi_init_uart
 jsr init_uart              \ initialize the uart
 sta AP5_disable            \ disable the ls245 on the AP5 to avoid conflicts with paged RAM
 jsr send_command           \ send ECHO OFF to ESP device
 equs "ATE0",&0D
 jsr read_response          \ wait for echo off to complete
 jsr test_paged_ram         \ check for paged ram
 beq ram_ok                 \ jump if ram found
 ldx #(error_no_pagedram-error_table)
 jmp error                  \ throw page ram error
.ram_ok
 jsr clear_buffer           \ initialize the receive buffer in paged ram
 lda save_a                 \ load driver function number
 and #&1F                   \ calculate jump address
 asl a
 tax
 lda entry_table,x
 sta zp
 lda entry_table+1,x
 sta zp+1
 jmp (zp)                   \ execute driver function
 
.flash
 jsr printtext
 equs "ElkWiFi rom flash utility",&0D,&EA
 jmp do_flash
 
\ Sets the UTC offser for NTP. There is no need to interact with the Wi-Fi module therefore called very early in code
\ One could argue this belongs in the ntp.asm code but this was much easier to place it here because a branch could be used here.
.entry_table
 equw init
 equw reset
 equw gmr
 equw cwlap
 equw cwjap
 equw cwqap
 equw cwsap
 equw cwmode
 equw cipstart
 equw cipmux
 equw cwlif
 equw set_buffer
 equw cipstatus
 equw cipsend
 equw cipclose
 equw cipserver
 equw cipsto
 equw ciobaud
 equw cifsr
 equw ciupdate
 equw ipd
 equw csyswdtenable
 equw csyswdtdisable
 equw mux_get_channel
 equw disable_enable
 equw cwlapopt
 equw sslbufsize
 equw cipmode
 equw ping
 equw set_time_out
 equw reserved
 equw reserved
 equw reserved
 
 \ send a byte to the wifi controller
 \ when terminated with &00 then don't finish command
 \ when terminated with &0D then finish with &0A code
.send_command
 pla
 sta zp
 pla
 sta zp+1
.sc0
 ldy #0
 inc zp
 bne sc1
 inc zp+1
.sc1
 lda (zp),y
 beq sc3
 jsr send_byte
 cmp #13
 bne sc0
.sc2
 lda #10
 jsr send_byte
.sc3
 inc zp
 bne sc4
 inc zp+1
.sc4
 jmp (zp)

 
.read_response
; just for debugging and emulation in BeebEm
; jsr printtext
; equs "Reading answer from ESP",&0D
; nop
; rts
 jsr uart_read_response
 jmp restore_env
 
.init \ init serial port and esp device
 jsr send_command
 equs "AT+RST",&0D
 jmp read_response
 
.reset \ reset esp8266
 jsr uart_hw_reset
 jmp read_response
 
.gmr \ get firmware version
 jsr send_command
 equs "AT+GMR",&0D
 jmp read_response
 
.cwlap \ list access points
 lda #8                 \ set time out
 sta time_out
 jsr send_command
 equs "AT+CWLAP",&0D
 jmp read_response

 \ Set options for CWLAP. In this driver version only two fixed options are available:
 \ x = 127 -> show all fields
 \ x = 7 -> only show encryption type, ssid and signal strenght
 \ Always sort by strongest signal
 \ Todo: make x variable and add y option for order
.cwlapopt                   \ options for list access points
 jsr send_command
 equs "AT+CWLAPOPT=1,",&00
 jsr send_param
 jsr send_crlf
 jmp read_response
  
.cwjap \ join access point
 \ x = hi byte param block, y=low byte param block
 lda #8                 \ set time out
 sta time_out
 jsr send_command
 equs "AT+CWJAP",&00
 ldy #0
 lda (paramblok),y
 beq cwjap_query
 lda #'='
 jsr send_byte
 jsr send_param_quoted
 lda #','
 jsr send_byte
 jsr send_param_quoted
 jmp cwjap_query_l1
.cwjap_query
 lda #'?'
 jsr send_byte
.cwjap_query_l1
 jsr send_crlf
 jmp read_response
 
.cwqap \ quit access point
 jsr send_command
 equs "AT+CWQAP",&0D
 jmp read_response
 
.cwsap \ set parameters of access point
.cifsr \ get ip address
 jsr send_command
 equs "AT+CIFSR",&0D
 jmp read_response
 
.cwmode \ wifi mode
 jsr send_command
 equs "AT+CWMODE",&00
 ldy #0
.cwmode_lbl1
 lda (paramblok),y
 beq cwjap_query
 lda #'='
 jsr send_byte
 bne last_param
 
.cipmode \ transfer mode
 jsr send_command
 equs "AT+CIPMODE",&00
 ldy #0
 beq cwmode_lbl1

.cipstart \ set up tcp or udp connection
 \ x = hi byte param block, y=low byte param block
 lda #16                    \ set long time out since DNS might take a while to time out
 sta time_out
 jsr send_command
 equs "AT+CIPSTART",&00
 ldy #0
 lda (paramblok),y
 beq cwjap_query
 lda #'='
 jsr send_byte
 lda mux_status
 beq cipstart_connect
 jsr send_param
 lda #','
 jsr send_byte
.cipstart_connect
 jsr send_param_quoted
 lda #','
 jsr send_byte
 jsr send_param_quoted 
 lda #','
 jsr send_byte
.last_param
 jsr send_param
 jsr send_crlf
 jmp read_response
 
.cipmux \ tcp/udp connections
 jsr cipmux_close_all
 jsr send_command
 equs "AT+CIPMUX",&00
 ldy #0
 lda (paramblok),y
 bne cipmux1
 jmp cwjap_query
.cipmux1
 and #&01
 sta mux_status
 lda #'='
 jsr send_byte
 jmp last_param
 
.cipmux_close_all
 pha
 ldx #4
.cipmux_close_l1
 jsr send_command
 equs "AT+CIPCLOSE=",&00
 txa
 clc
 adc #'0'
 jsr send_byte
 jsr send_crlf
 lda #&00
 sta mux_channel,x
 dex
 bpl cipmux_close_l1
 pla
 rts
 
.mux_get_channel
 jsr restore_env
 lda mux_status
 beq no_mux
 ldy #4
.mux_get_loop
 lda mux_channel,y
 beq av_channel
 dey
 bpl mux_get_loop
 sec
 rts
.no_mux
 ldy #&ff
 clc
 rts
.av_channel
 lda #&2a
 sta mux_channel,y
 sec
 rts
 
.cwlif \ check joined devices ip
.cipstatus \ tcp/ip connection status
 jsr send_command
 equs "AT+CIPSTATUS",&0D
 jmp read_response
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

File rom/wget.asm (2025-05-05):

\ WGET command
\ Syntax:    *WGET [-T | -X | -A | -P | -U | -S | -F | -D] <url> [address]
\ Option:    -T        optional    print the downloaded file directly on the screen, newline by &0D
\            -X        optional    print the downloaded file directly on the screen, newline by &0A
\            -A        optional    the file has an ATM header
\            -P        optional    the file has an Atom-in-PC header
\            -U        optional    the file is a UEF file
\            -S        optional    the file is a sideways rom, specify banknumber in address parameter
\            -F        optional    force file to load in host if second processor present
\            -D        optional    the file is generic data
\            url       required    the url of the file, including http(s)://
\            address   optional    load address of the file
\ The address will override the load address in the ATM header (if any). It will be ignored with the -T parameters
\ since that option does not store any contents in memory. If the file has no ATM header the address is required.
\ 
\ -D option
\ This option copies data in the same way as the -U UEF file option, but since no assumptions about the content of the
\ data can be made, a simple header is required to allow user programs to easily access the data. This allows the data
\ to remain in paged RAM, leaving Electron RAM free for user programs.
\ The first four bytes of RAM bank 1 specify the start and end of the data. In the future, additional bytes after this 
\ could be defined to provide new functionality. Avoiding a fixed start address provides some future proofing.
\ &0000 - &0001  <START> Address of first byte of data. 
\ &0002 - &0003  <END>   Address of first free byte of memory after the data.
\ Reading and over-writing of data can be accomplished using the information in the first four bytes.
\ Possible future enhancements:
\ Data from multiple WiFi accesses could be stored consecutively, in which case an equivalent four byte header could 
\ appear at the end of the first data block to identify the start and end of a subsequent data block.
\ The following commands could be developed to provide enhanced access to the data.
\ *DINSERT <n> <source_addr> <dest_addr> 
\ Insert n bytes of data stored in main RAM at <source_addr> into RAM bank 1 starting
\ from <dest_addr>. Data after <dest_addr> is shifted in memory to avoid over-writing data.
\ *DFIND <n> <key_addr> <found_addr> <start_addr> <end_addr> 
\ Search for matching n bytes of data stored in main RAM at <key_addr>. If a match is found, its RAM bank 1 address
\ is stored in the two bytes in main RAM pointed to by <found_addr>. <found_addr> is set to zero if no match is found. 
\ <start_addr> and <end_addr> are optional arguments. If they are not present then the values at RAM bank 1 &0000 and
\ &0002 will be used (<START> and <END>).
\
\ (c) Roland Leurs, July 2020

                dflag = heap + &F3      \ 1 byte
                fflag = heap + &F4      \ 1 byte as tube transfer flag, 0= host transfer, &FF=tube transfer
                proto = heap + &F5      \ 1 byte
                newln = heap + &F6      \ 1 byte
                clptr = heap + &F7      \ 1 byte
                index = heap + &F8      \ 1 byte
                sflag = heap + &F9      \ 1 byte
                tflag = heap + &FA      \ 1 byte
                aflag = heap + &FB      \ 1 byte
                pflag = heap + &FC      \ 1 byte
                uflag = heap + &FD      \ 1 byte
                laddr = heap + &FE      \ 2 bytes

                data_pr_y = 4           \ ram bank 1 pointer to start of data. This value can be updated in future
                                        \ code without breaking backwards compatibility.
                tubeflag  = &27A        \ (Osbyte &EA = 0 if no tube, &FF if tube)
                tubereg   = &FCE5       \ address of tube data transfer register on electron
                tubeID    = &E0         \ a number between &C0 and &FF that is my ID for claiming tube interface
                                        \ needs to be sent with bit 6 = 0, ie. between &80 and &BF to release tube
                                        \ unless a run command 4 has been sent

.wget_cmd                   \ start wget command
 lda tubeflag               \ fflag will be &FF if tube present, unless cleared later
 sta fflag
 lda #0                     \ initialize flags and address
 sta tflag
 sta sflag
 sta aflag
 sta pflag
 sta uflag
 sta dflag
 sta proto                  \ default no ssl (i.e. http)
 sta laddr
 sta laddr+1
 lda #&0D                   \ set new line character
 sta newln                  \ can be overwritten by -U flag

.wget_l1
 jsr skipspace1             \ forward Y pointer to first non-space character
 jsr read_cli_param         \ read first parameter from command line
 cpx #&00                   \ test if any parameter given, x will be > 0
 bne wget_read_params       \ continue if one parameter is on the command line
 jsr printtext              \ no parameter, print a message
 equs "Usage: WGET [-TXAPUSFD] <url> [address]",&0D,&EA
 jmp call_claimed           \ end of command

.wget_read_params
 lda strbuf                 \ read first character of the parameter
 cmp #'-'                   \ check for a dash
 bne wget_read_uri          \ it's not a dash so we consider it the url
 lda #0                     \ clear fflag when other flags (including F) set to prevent tube transfers
 sta fflag

 lda strbuf+1               \ read character of option
 ora #&20                   \ convert to lowercase
 cmp #'f'                   \ check for F (force host load- already cleared above)
 beq wget_l1
 cmp #'t'                   \ check for T (text file)
 beq wget_option_t          \ jump if T
 cmp #'a'                   \ check for A (ATM header)
 beq wget_option_a          \ jump if A
 beq wget_option_a          \ jump if A
 cmp #'x'                   \ check for X (unix text file)
 beq wget_option_x          \ jump if X
 cmp #'p'                   \ check for P (Atom-in-PC header)
 beq wget_option_p          \ jump if P
 cmp #'u'                   \ check for U (UEF file)
 beq wget_option_u
 cmp #'d'                   \ check for D (Generic data file)
 beq wget_option_d
 cmp #'s'                   \ check for S (Sideway rom)
 beq wget_option_s
 ldx #(error_bad_option-error_table)
 jmp error                  \ unrecognized option, throw an error

.wget_option_x              
 lda #&0A                   \ load alternative new line character
 sta newln                  \ write to workspace
.wget_option_t
 lda #1                     \ set flag to 1
 sta tflag
 bne wget_l1                \ jump always

.wget_option_a
 lda #1                     \ set flag to 1
 sta aflag 
 jmp wget_l1                \ jump always
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

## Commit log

2020-08-07 Added KiCad files to git repository.
2020-08-08 *PRD command accepts second parameter for 64K bank selection ECHO OFF send to ESP8266 before each command Test for page ram availability at start of driver Test for wifi enabled at start of driver
2020-08-08 OSWORD call &65 implemented to call the WiFi driver from user applications.
2020-08-08 WGET modifications: - Bugfix after http header check - Test for connection error - Added -P for Atom-in-PC header
    [driver.asm, wget.asm]
2020-08-09 Time-out setting integrated in driver and removed from * commands Changed receive data routine for hi-res graphics modes. It almost works.
2020-08-09 Moved the UART to address &FC3x to avoid clashes with AQR and DataCentre hardware Added write to MSR and LSR to block the reset for the UART, so the WiFi can stay disabled after a (hard) reset.
2020-08-13 Disable interrupts during receiving data from the ESP8266. This allows the WiFi to be used in high resulotion graphic modes.
2020-08-16 Added crc16 check to the update command. Also added the tools 'erase' and 'program' to manually reflash the EEPROM in case of emergency.
2020-08-18 Added the sources to match the definitive version; development system is also modified to have the correct memory assignments.
    [driver.asm, erase.asm, program.asm]
2020-08-21 Bugfix in prd when start address is not aligned to 0 or 8.
    [pdump.asm]
2020-08-21 Bugfix in join command where prompted password results in 'device not responding' error.
2020-08-24 Bugfixes: 1. Do not display the WiFi logo when WiFi is disabled 2. Perform a hard reset of the ESP8266 after power on
    [serial.asm]
2020-08-24 Added the *DISCONNECT command to close a server connection that has been left open after an error condition. Close server connection in WGET when encountering a HTTP error or buffer full error.
    [wget.asm]
2020-08-25 Revert "Added the *DISCONNECT command to close a server connection that has"
    This reverts commit fd1cf02e454bd15a709aaa01f7dae63ba0db5662.
    [wget.asm]
2020-08-25 Revert "Revert "Added the *DISCONNECT command to close a server connection that has""
    This reverts commit 8de70a855ab3a591b1282e14a2c16042ed9a226e.
    [wget.asm]
2020-08-25 Fixed the bug of the terminating &00 after the GET request header. Clear all ULA interrupts before enabling the interrupts after uart_read_response.
    [serial.asm, wget.asm]
2020-09-06 Removed kicad files
2020-09-14 Started working on printer driver
2020-09-15 Added parsing serial data, there is an error in 24bit mul10 routine!
    [serial.asm, wget.asm]
2020-09-17 Fixed the bug in MUL10 Added setup of serial port A
    [serial.asm, wget.asm]
2020-09-19 Added network printing routines. Not completely working yet.
2020-09-21 Finished printing routine
2020-09-22 Updated the user manual with new commands (MENU, PING, PRINTER and SETSERIAL) New driver functions added (CIPMODE and PING) Corrected parameter text for CWMODE function in driver Added chapter about 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
2021-01-08 Update routines.asm
    Changed print_logo routine to use user-defined character to print instead of direct store in memory. Also added support for mode 7 display.
2021-01-09 Update flash.asm
    Check whether master ram board is present when jumping into reset routine in OS
    [flash.asm]
2021-01-10 Update flash.asm
    Changed reset code to work with master ram board regardless of whether any other application has used the master ram flag at &27F.
    [flash.asm]
2021-01-16 Add second processor support to wget.asm (#4)
    * Update wget.asm
    * Update wget.asm
    * Update wget.asm
    * Update wget.asm
    * Update wget.asm
    * Update wget.asm
    * Update wget.asm
    * Update wget.asm
    * Update wget.asm
    Add support for second processor.
    If present data transfers will go to the second processor unless flags are set. The load address will default to PAGE (&800) unless supplied.
    A new flag F will force loading into the host processor. Any other flags will do the same.
    If the load address is >= &8000 it is a ROM and a run command will be sent to the second processor. Care must be taken that the correct load address is supplied, ie. usually &8000 or &B800. If it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
    [wget.asm]
2021-05-30 Update from version 0.23 to 0.26. I didn't push some updates inbetween those versions and I don't exactly remember what has changed. One important thing is that version 0.26 has some fixes to make it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
    [driver.asm, flash.asm, pdump.asm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]
2021-10-30 Added extra line feed in help text Fixed a bug that re-enables the WiFi after a reset
    [driver.asm]
2022-03-26 Bugfix in serial_setup_a where due to a typo one register of the B port is addresses Feature: use spaces in parameters (e.g. network names) by using quotes.
    [serial.asm]
2022-05-06 Feature request by John Kortink: * commands case insensitive
2022-11-04 Make command line case insensitive
2023-07-29 Modified update command to support TI16C2552 UART. ROM imaged needs to be in lower ROM banks.
2023-09-26 Added driver function to set time out to allow slower servers. OSWORD&65 calls return with X and Y saved in &F0 and &F1.
2023-11-18 Add data option (#7)
    * Add ROM files to gitignore
    * Fix comment
    * Add command options to select RAM bank
    * Add documentation for new data option
    * Fix cut and paste error in comment
    * Fix comment typo
    * Add google translate of comment
    * Fix comment typo
    * Update help info with RAM bank selection option
    * Set -D option to mimic -U option
    * Initialise pointers for storing generic data in RAM bank 1
    * Fix typo
    * Use value not location
    * Realyy make D the same as U
    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
    [serial.asm, wget.asm]
2024-11-17 Firmware version 1.3.0.2 added
    Just in case you break your ESP module or get a module with an incompatible or broken firmware. Use the flash_esp.sh script on Linux to program the module. Requires esptool.py and a suitable programmer board. It's not possible to program the ESP module on the WiFi board.
2025-05-05 Fixed compatibility bug with RAMUTILS; multiplexing is now disabled in the WiFi driver (was never used anyways). Bugfix in calculating the end address of WGET -D option. Now &FD02/&FD03 point to firs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
    [wget.asm]
